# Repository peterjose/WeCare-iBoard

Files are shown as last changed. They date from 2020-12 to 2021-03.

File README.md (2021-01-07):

# WeCare-iBoard
WeCare-iBoard is an interactive board developed by the Team Hugo of University of Saarland.
The project is supported by the Human-Computer Interaction group of Saarland University.

The theme of the project is to build interactive robots that bring us together, especially during the Covid situation.

## Description
WeCare-iBoards work in pairs, one for each user. Connected wirelessly, the boards let the two users interact with each other. The user places portable cubes on top of the board and this activates the other iBoard. The iBoard2 actuates, following the placement of the portable cubes on iBoard1, which makes this device tangible and lets users feel more connected. The project aims at letting the users transfer emotions ideally and also do other fun activities like play games. The iBoards are originally designed to be mounted on the wall but later can also be scaled for some portability. 

## Project documentation
Project Documentation can be found under the directory "doc"

## General Commit rules to be followed
* Create branches if working on existing project directories
* Create new folders for storing unit test codes 

## Documentation naming convention
WeCare_iBoard_FileName.extension

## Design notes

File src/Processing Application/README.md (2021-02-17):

# Processing Application
An application to support interfacing with iBoard. Using this application users can send a text message to each other’ board.
The text message is decoded to a symbol/icon, then it is transferred to the other users board. The translation is also visible on the virtual board available on the app.

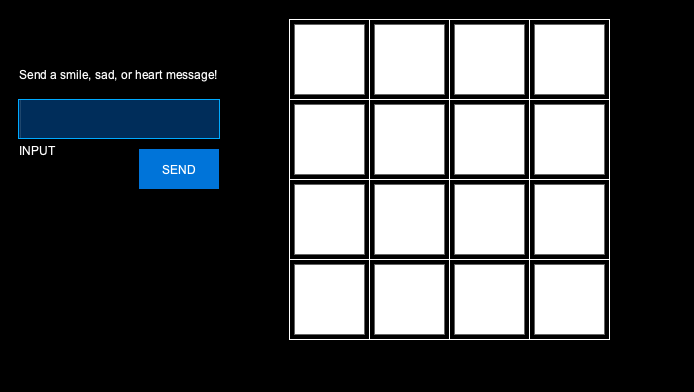
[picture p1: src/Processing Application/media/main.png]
alt main


How it works:

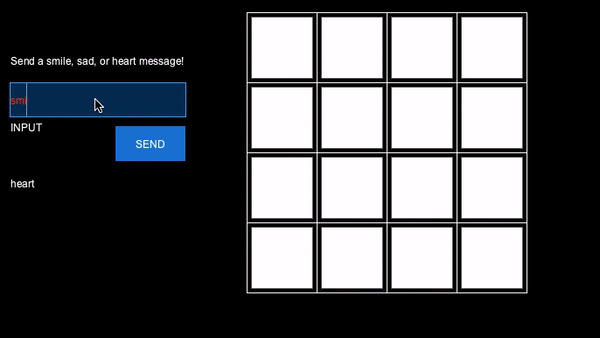
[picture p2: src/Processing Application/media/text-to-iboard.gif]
Alt app


### TODO:
Set a communication channel, board <-> app

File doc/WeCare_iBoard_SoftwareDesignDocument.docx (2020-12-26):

WeCare i-Board

Software Design Document

By

Team Hugo

## 1. Project Overview

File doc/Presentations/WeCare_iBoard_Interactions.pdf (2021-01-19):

# Interactions

# User Scenarios

# List

## - Emoji - Play Tic-Tac-Toe - Remote Collaboration(Task status bar) - *Modified Marble Answering Machine

# Emoji

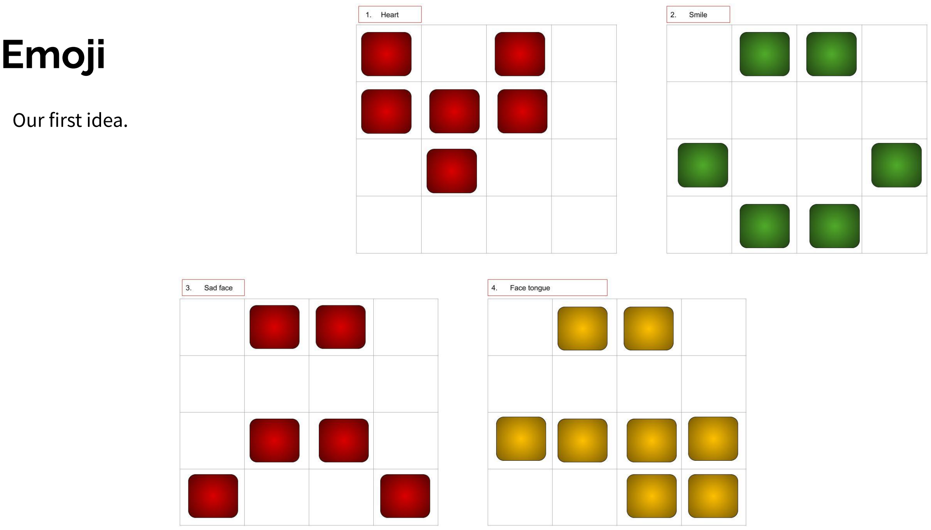
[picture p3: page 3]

Our first idea.

# Play a Game - tic-tac-toe

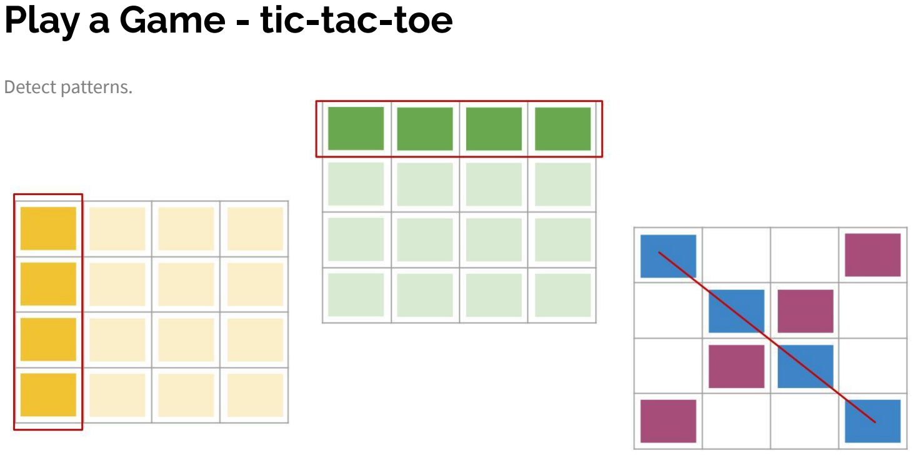
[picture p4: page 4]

Detect patterns.

# Remote Collaboration

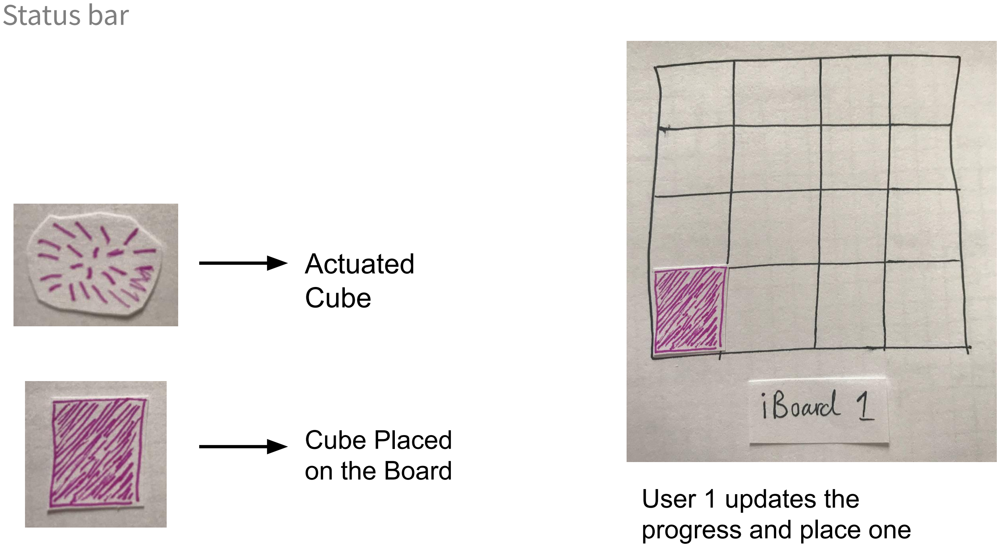
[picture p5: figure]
Status bar; Actuated Cube; Cube Placed on the Board; User 1 updates the progress and place one

cube on the board.

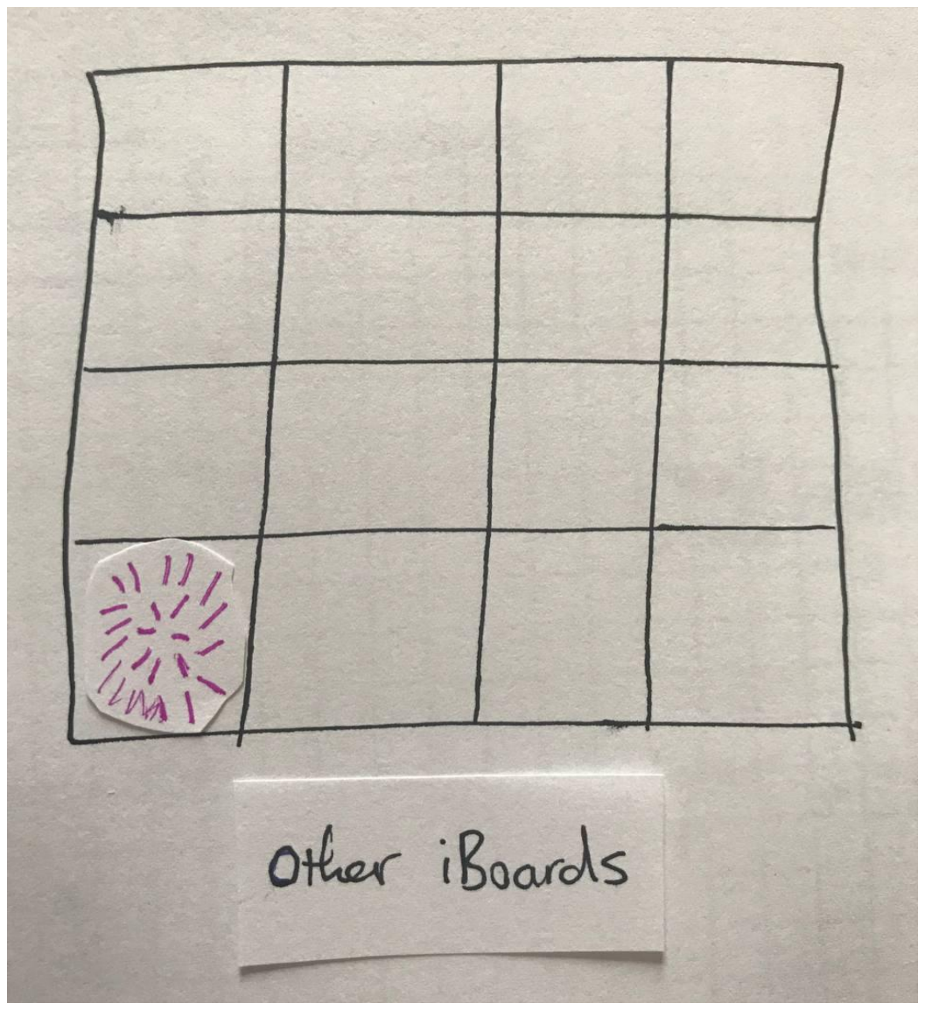
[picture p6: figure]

Other boards get the
update.

# Remote Collaboration

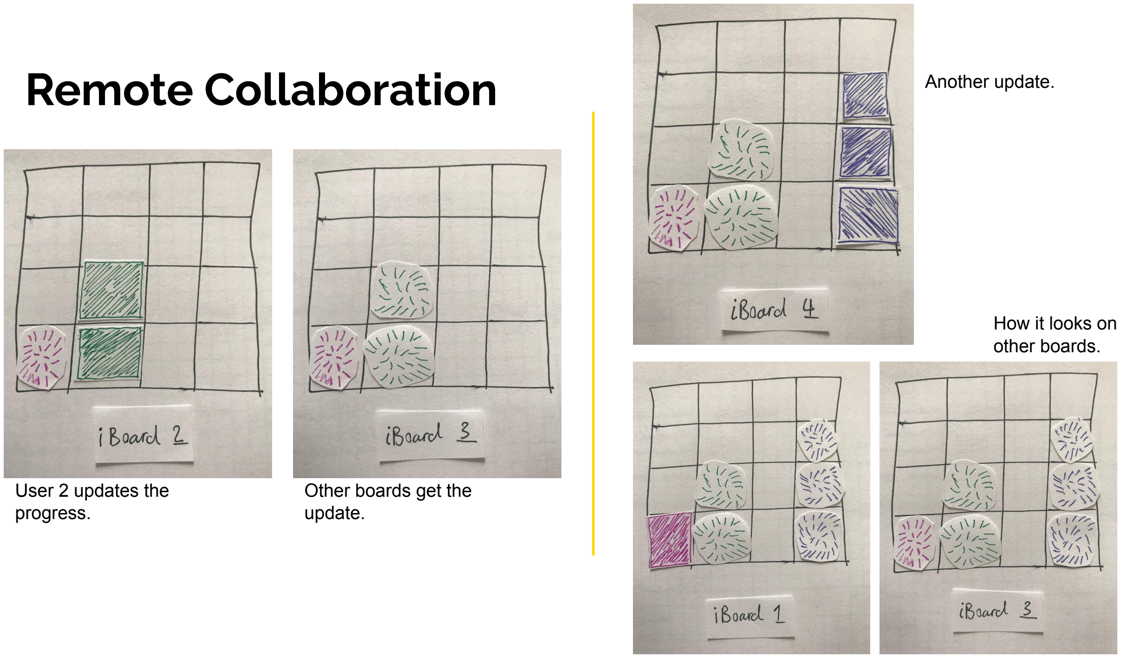
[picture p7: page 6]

User 2 updates the
progress.

Other boards get the
update.

Another update.

How it looks on
other boards.

# *Modified Marble Answering Machine

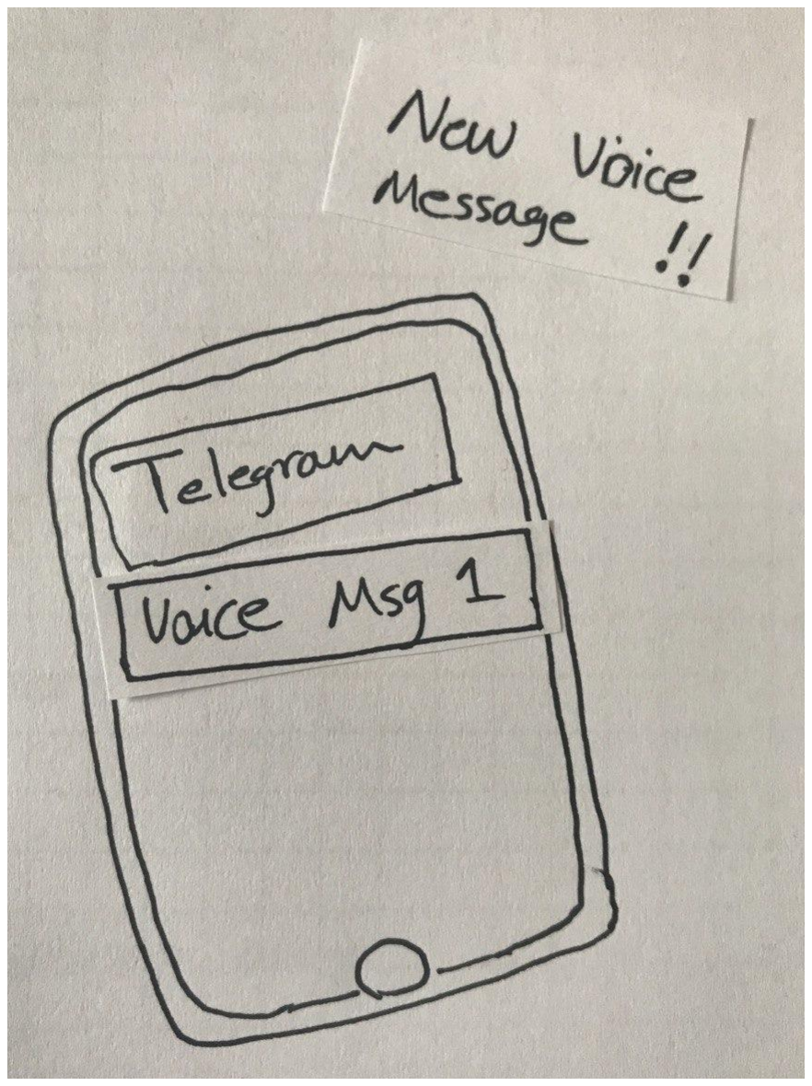
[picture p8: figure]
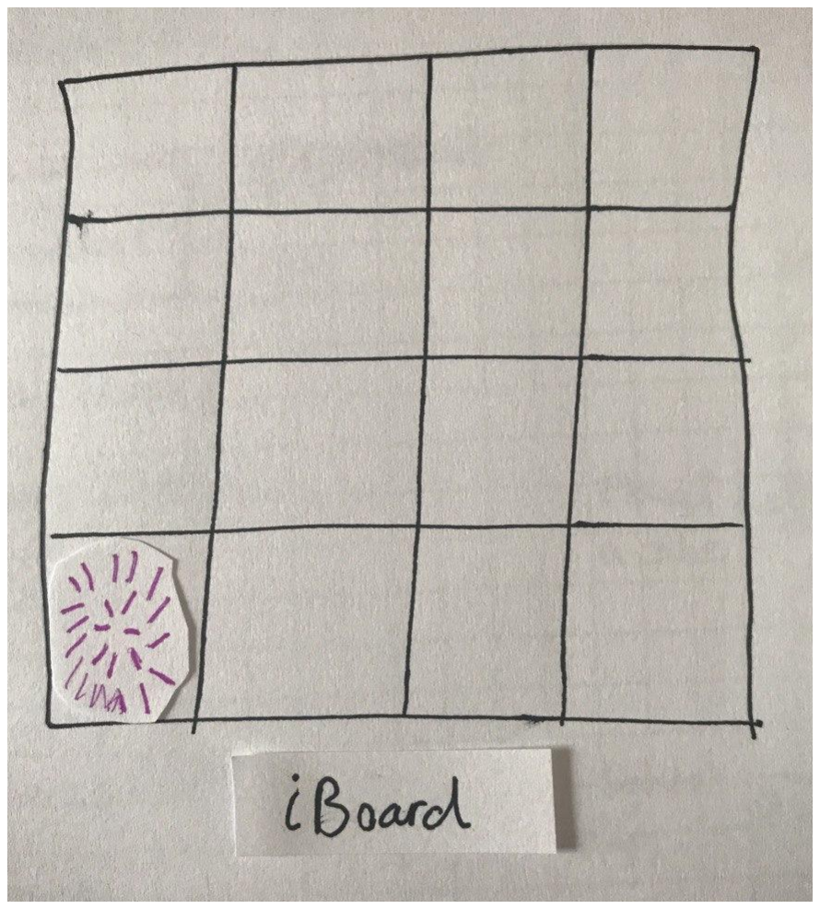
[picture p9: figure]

New voice
messages
arrives.

One cube pops up.

# *Modified Marble Answering Machine

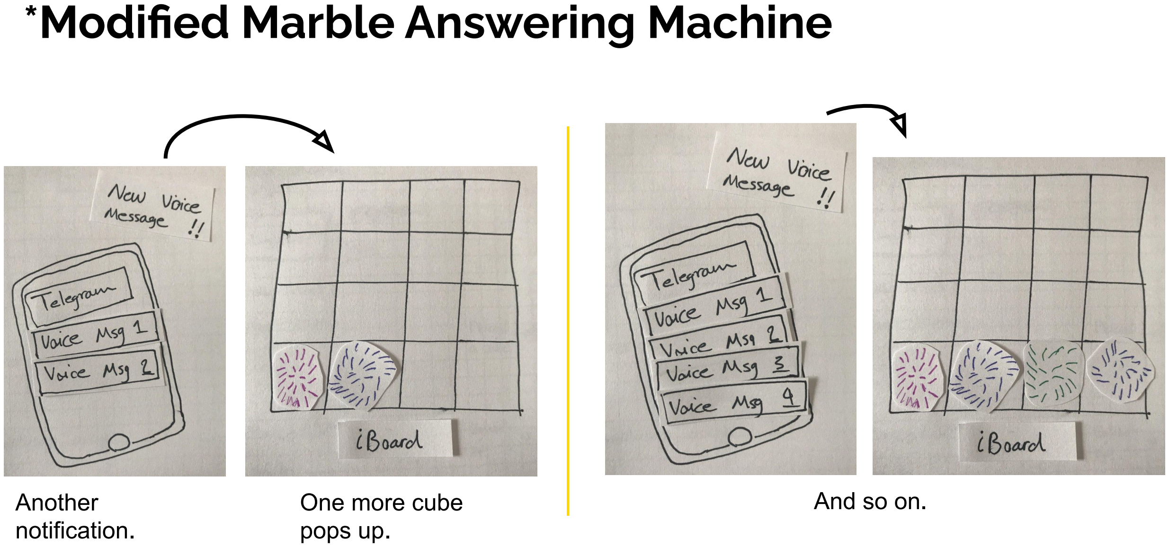
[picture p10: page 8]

Another
notification.

One more cube
pops up.

And so on.

# *Modified Marble Answering Machine

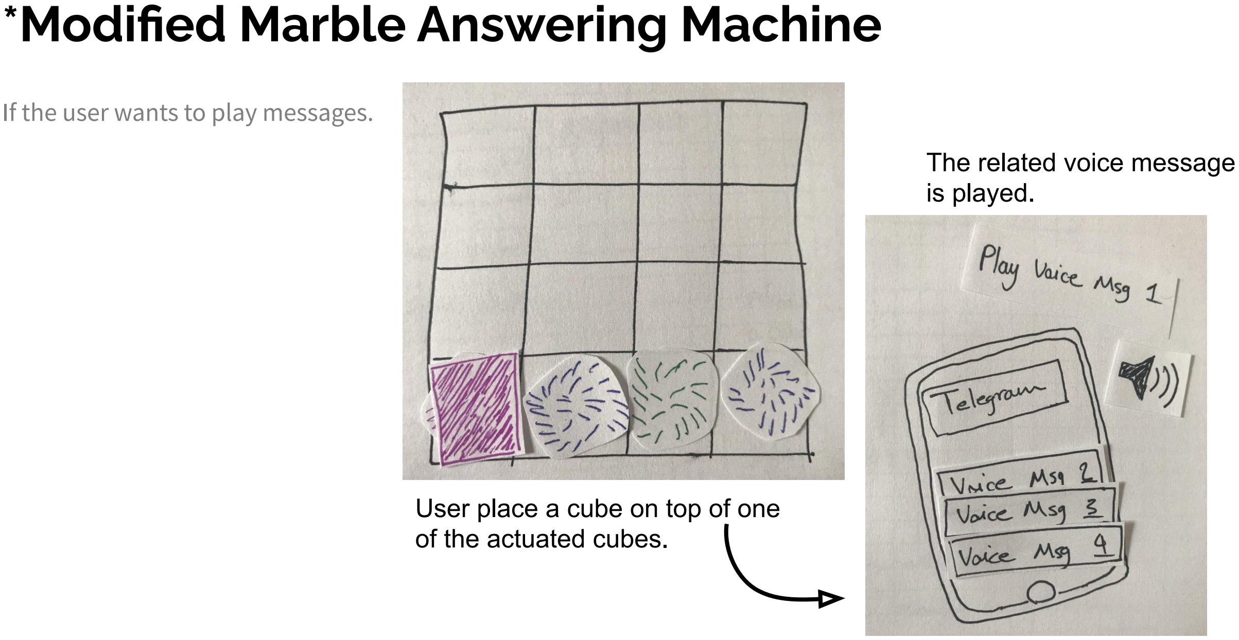
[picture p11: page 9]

If the user wants to play messages.

User place a cube on top of one of the actuated cubes.

The related voice message
is played.

# *Modified Marble Answering Machine

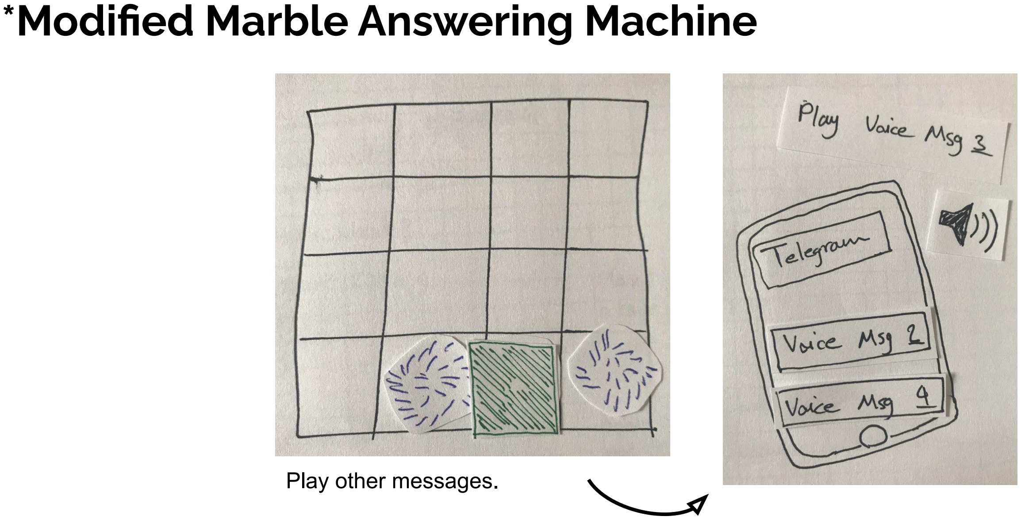
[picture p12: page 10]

Play other messages.

# Mode Switch

### - Hard code - reprogram the board for each scenario - Use buttons - Mode switch patterns - Easy transition

# Mode Switch

## Using Patterns

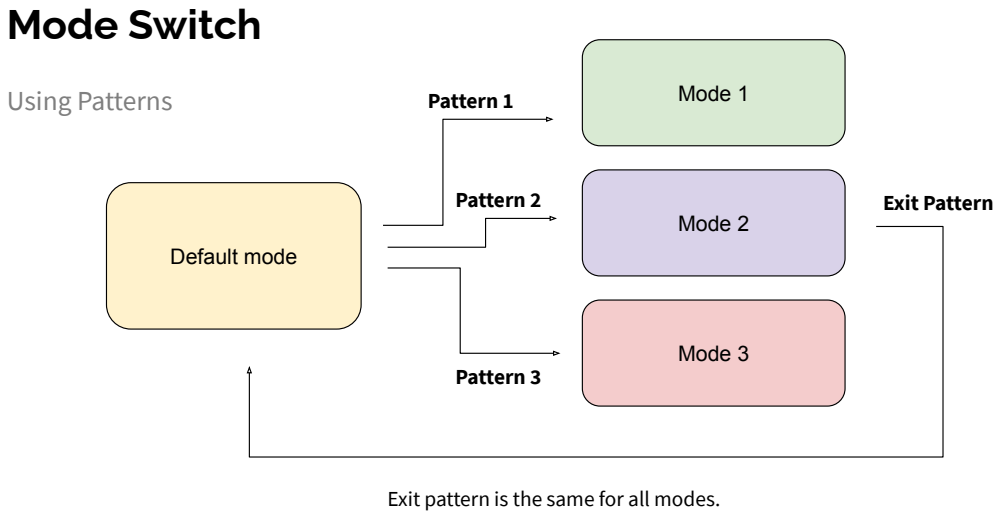
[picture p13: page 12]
Default mode; Mode 1; Mode 2; Mode 3; Exit Pattern; Pattern 1; Pattern 2; Pattern 3

Exit pattern is the same for all modes.

# Mode Switch

## Using Patterns

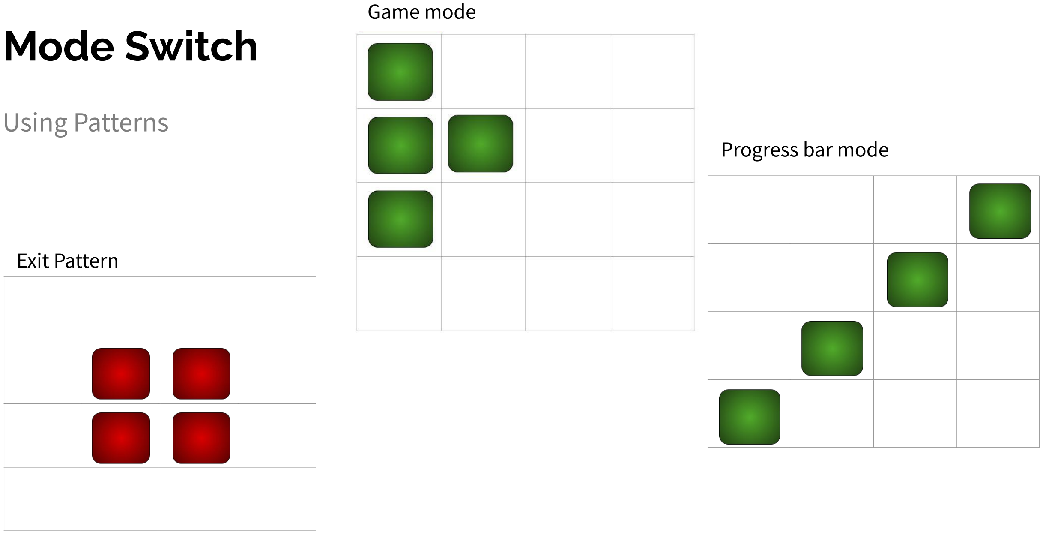
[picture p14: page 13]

Progress bar mode

Exit Pattern

Game mode

# Transition between modes

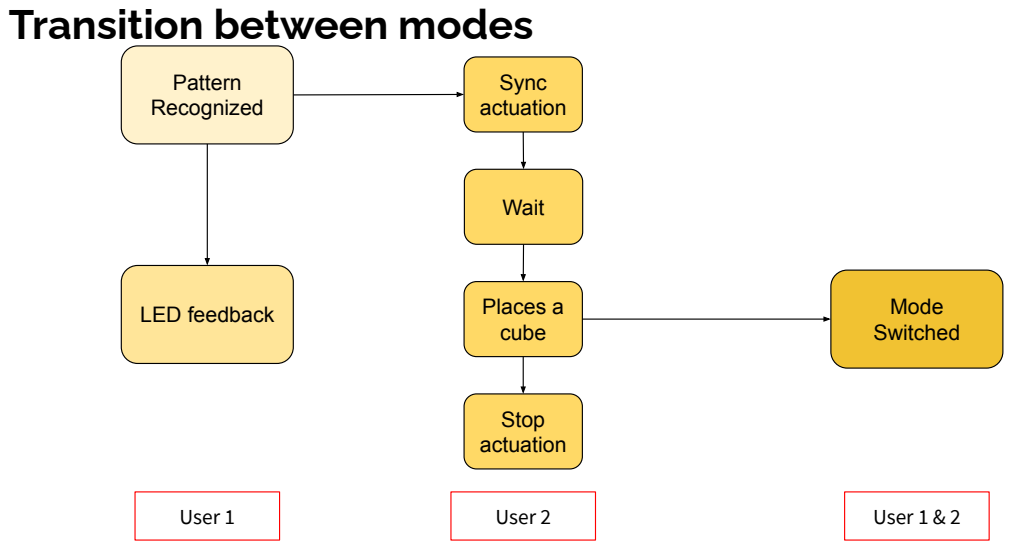
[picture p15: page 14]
Pattern Recognized; LED feedback; Sync actuation; Wait; Places a cube; Mode Switched; User 1; User 2; User 1 & 2; Stop actuation

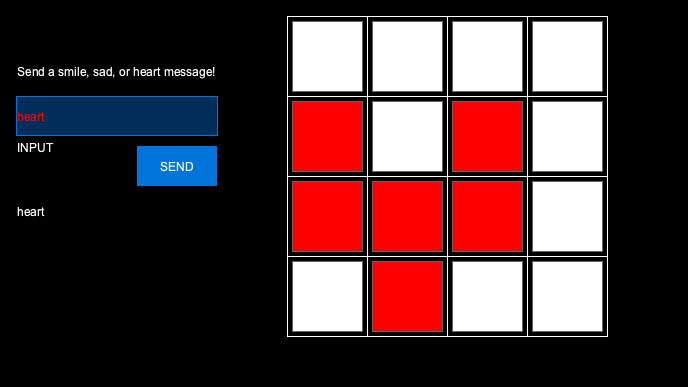
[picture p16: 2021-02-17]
src/Processing Application/media/heart.png

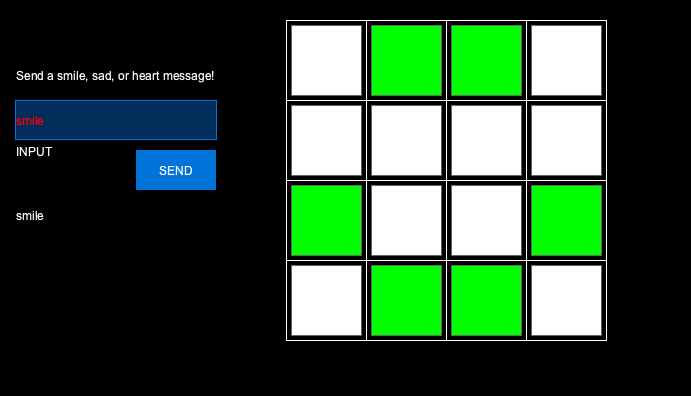
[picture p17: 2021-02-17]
src/Processing Application/media/smile.png

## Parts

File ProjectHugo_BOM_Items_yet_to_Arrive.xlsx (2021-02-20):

BILL OF MATERIALS ROBOTIC SEMINAR
GROUP NAME | Project Hugo
PART COUNT | 9
TOTAL COST | €148.64
PART NUMBER | PART NAME | DESCRIPTION | PART IMAGE | QUANTITY | UNITS | SUPPLIER / MANUFACTURER / LINK | UNIT COST | TOTAL PART COST
B01N2N7LZA | Arduino Mega shield | To make the connections to the modular peices |  | 2 | Nos | https://www.amazon.de/-/en/Wingo-Engineer-Baite-02/dp/B01N2N7LZA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 | €16.00 | €32.00
B01EV70C78 | Jumper wires | For connection betweeen components 40x M-M 40x F-M 40x F-F Header strips |  | 2 | Nos | https://www.amazon.de/-/en/KeeYees-120pcs-Jumper-Arduino-Raspberry/dp/B07KCD7GS7?s=ce-de | €8.00 | €16.00
 |  |  |  |  |  |  | Total | €48.00
 |  | Lab Consumables | (Order only if Not available in the LAB)
B07GXN2521 | JST connector(L) | For the power supply (in total 32 peices) |  | 4 | Nos | https://www.amazon.de/ILS-Micro-1-5mm-Connector-Cables/dp/B07GXN2521 | €8.71 | €34.84
B00KKVJ1H2 | Power Supply 5v 20A | For powering all the board |  | 1 | Nos | https://www.amazon.de/Supply-Netzteil-WS2801-WS2812-WS2812B/dp/B00KKVJ1H2 | €32.00 | €32.00
168284GR | Soldering dot Board | Custom PCB boards |  | 1 | Nos | https://www.amazon.de/dp/B08BR2CQRX | €16.00 | €16.00
B07PNYJDZ7 | Acrylic Glue(L) | Glue to stick all the parts of the board |  | 1 | Nos | https://www.amazon.de/-/en/S-PolyBond%C2%AE-Acrylic-plexiglass-adhesive-suitable/dp/B07PNYJDZ7 | €9.90 | €9.90
B07Y1TJH5R | Power Supply cables | Power cable of the power supply |  | 1 | Nos | https://www.amazon.de/dp/B07Y1TJH5R | €6.00 | €6.00
B00XZ7IEAS | Heat shrink tube(L) | For making the wire connection proper and |  | 1 | Nos | https://www.amazon.de/-/en/Aurora-trading-Shrink-Tubing-Choose-colours/dp/B00XZ7IEAS | €1.90 | €1.90
 |  |  |  |  |  |  | Sub Tatal | €100.64
 |  |  | TOTAL PARTS | 9 |  |  | TOTAL | €148.64

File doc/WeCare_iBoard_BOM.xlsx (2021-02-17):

BILL OF MATERIALS ROBOTIC SEMINAR
GROUP NAME | Project Hugo
PART COUNT | 109
TOTAL COST | €447.75
PART NUMBER | PART NAME | DESCRIPTION | PART IMAGE | QUANTITY | UNITS | SUPPLIER / MANUFACTURER / LINK | UNIT COST | TOTAL PART COST
B089SP1MSN | Acrylic Sheets | For the board design and gears |  | 4 | Nos | https://www.amazon.de/-/en/Plexiglas%C2%AE-versatile-unbreakable-branded-white-translucent/dp/B089SP1MSN | €15.00 | €60.00
B075QM9GKW | Plywood Sheets | For Outer body of both boxes(100 sq cm) |  | 10 | Sheets | https://www.amazon.de/-/en/Creative-Plywood-Chipboard-Pyrography-Openwork/dp/B075QM9GKW | €16.45 | €16.45
RBS10195 | Micro Servo | Actuating the blocks of the interactive display |  | 35 | Nos | https://www.roboter-bausatz.de/246/sg90-9g-micro-servomotor | €2.00 | €70.00
B01N2N7LZA | Arduino Mega shield | To make the connections to the modular peices |  | 2 | Nos | https://www.amazon.de/-/en/Wingo-Engineer-Baite-02/dp/B01N2N7LZA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 | €16.00 | €32.00
A000067 | Arduino Mega | Micro controller that controls the sensors and actuators |  | 2 | Nos | https://www.amazon.de/Mikrocontroller-ATmega2560-ATMEGA16U2-USB-Kabel-Kompatibel/dp/B01MA5BLQI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 | €15.00 | €30.00
B075F3KG2K | Reed Switch | To sense the block placement by the user (in total 32 peices) |  | 4 | Nos | https://www.amazon.de/EsportsMJJ-Wechsler-Magnetschalter-Switches-Switch/dp/B075F3KG2K?hvadid=354652109717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 | €4.99 | €19.96
B01N0GIHFG | Neo Pixel 1 | To highlight the activated block as per design (in total 32 peices) |  | 1 | Nos | https://www.amazon.de/-/en/CHINLY-Pieces-WS2812B-Addressable-Heatsink/dp/B01N0GIHFG?s=lighting | €16.00 | €16.00
B01EV70C78 | Jumper wires | For connection betweeen components 40x M-M 40x F-M 40x F-F Header strips |  | 2 | Nos | https://www.amazon.de/-/en/KeeYees-120pcs-Jumper-Arduino-Raspberry/dp/B07KCD7GS7?s=ce-de | €8.00 | €16.00
S-08-04-N | Permanent Magnet | This is used to activate the reed switch sensor (in total 32 peices) |  | 40 | Nos | https://www.supermagnete.de/scheibenmagnete-neodym/scheibenmagnet-8mm-4mm_S-08-04-N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 | €0.35 | €14.00
B06Y1ZPNMS | ESP8266 | Controller that is used for wireless connection |  | 2 | Nos | https://www.amazon.de/AZDelivery-NodeMCU-ESP8266-ESP-12E-Development/dp/B06Y1ZPNMS?hvadid=310638483583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 | €6.00 | €12.00
B00IYUWT2A | Resistors | 10 KOhm for the sensor design 30x Resistors pack (in total 32 peices) |  | 2 | Nos | https://www.amazon.de/Widerstand-St%C3%BCck-Kohleschicht-Widerst%C3%A4nde-Resistor/dp/B00IYUWT2A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 | €3.15 | €6.30
 |  |  |  |  |  |  | Total | €292.71
 |  | Lab Consumables | (Order only if Not available in the LAB)
B07GXN2521 | JST connector(L) | For the power supply (in total 32 peices) |  | 4 | Nos | https://www.amazon.de/ILS-Micro-1-5mm-Connector-Cables/dp/B07GXN2521 | €8.71 | €34.84
B00KKVJ1H2 | Power Supply 5v 20A | For powering all the board |  | 1 | Nos | https://www.amazon.de/Supply-Netzteil-WS2801-WS2812-WS2812B/dp/B00KKVJ1H2 | €32.00 | €32.00
168284GR | Soldering dot Board | Custom PCB boards |  | 1 | Nos | https://www.amazon.de/dp/B08BR2CQRX | €16.00 | €16.00
AK-B7116091(L) | Micro USB cable | USB cable to connect the ESP for programming and powering |  | 2 | Nos | https://www.amazon.de/Anker-Ladekabel-vergoldeten-Steckern-Smartphones/dp/B01DEMTOQ6?hvadid=309827211017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 | €8.00 | €16.00
B075LMP74F | Conductive copper wire(L) | For electrical wiring |  | 1 | Nos | https://www.amazon.de/-/en/0-25-Plated-Copper-Insulation-Wrapping/dp/B075LMP74F | €15.10 | €15.10
B07PNYJDZ7 | Acrylic Glue(L) | Glue to stick all the parts of the board |  | 1 | Nos | https://www.amazon.de/-/en/S-PolyBond%C2%AE-Acrylic-plexiglass-adhesive-suitable/dp/B07PNYJDZ7 | €9.90 | €9.90
B00DCMK102 | Soldering Iron(L) | For soldering |  | 1 | Nos | https://www.amazon.de/Unbekannt-Fein-L%C3%B6tkolben-230V-30W-L%C3%B6tkolben/dp/B00DCMK102?hvadid=308574982278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 | €7.80 | €7.80
B07Y1TJH5R | Power Supply cables | Power cable of the power supply |  | 1 | Nos | https://www.amazon.de/dp/B07Y1TJH5R | €6.00 | €6.00
B07K8PQ4B5 | Breadboards(L) | For testing |  | 1 | Nos | https://www.amazon.de/dp/B07K8PQ4B5 | €4.80 | €4.80
B07QKYGGJ4 | Soldering Led(L) | For soldering |  | 1 | Nos | https://www.amazon.de/Starnearby-Kolophonium-Flussmittel-L%C3%B6tmittel-Durchmesser/dp/B07QKYGGJ4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 | €4.60 | €4.60
2615GG01JA | Glue sticks(L) | Glue sticks for glue gun |  | 1 | Nos | https://www.amazon.de/-/en/Multipurpose-Accessory-Temperature-Plastic-Ceramics/dp/B004G98SSC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 | €3.10 | €3.10
4C-RNJD-GS1W | Cable Tie(L) | To arrange the cables properly |  | 1 | Nos | https://www.amazon.de/-/en/Cable-ties/dp/B007N2MQQ4 | €3.00 | €3.00
B00XZ7IEAS | Heat shrink tube(L) | For making the wire connection proper and |  | 1 | Nos | https://www.amazon.de/-/en/Aurora-trading-Shrink-Tubing-Choose-colours/dp/B00XZ7IEAS | €1.90 | €1.90
 |  |  |  |  |  |  | Sub Tatal | €155.04
 |  |  | TOTAL PARTS | 109 |  |  | TOTAL | €447.75

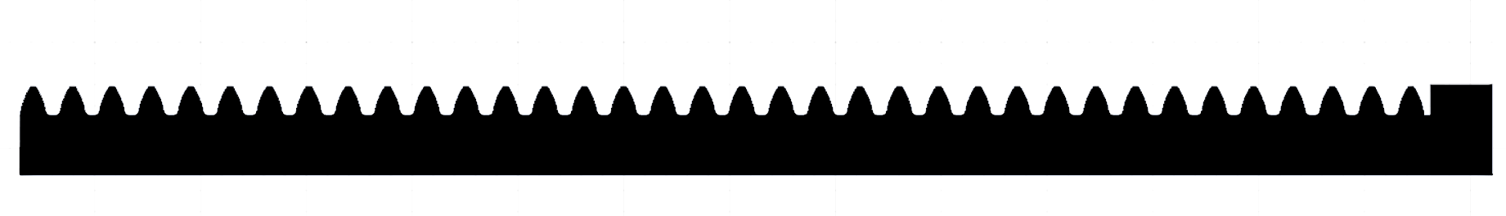
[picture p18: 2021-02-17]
3d-models/Individual Parts/Laser Cut Files/Rack/Rack2.png

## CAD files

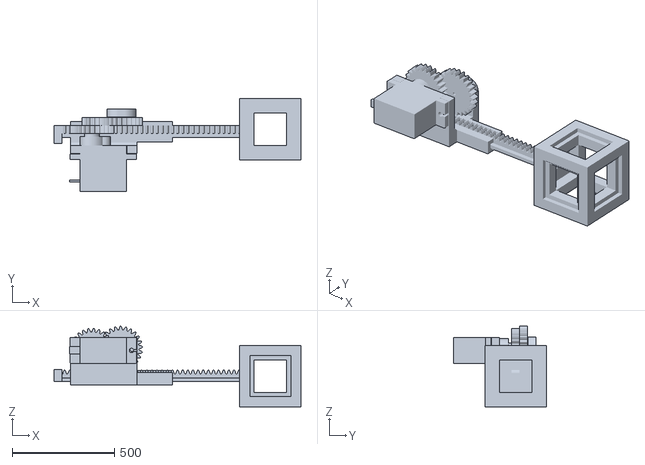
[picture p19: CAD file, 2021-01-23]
3d-models/Hugo Body Final.stl
1209.5 x 453.2 x 394.3

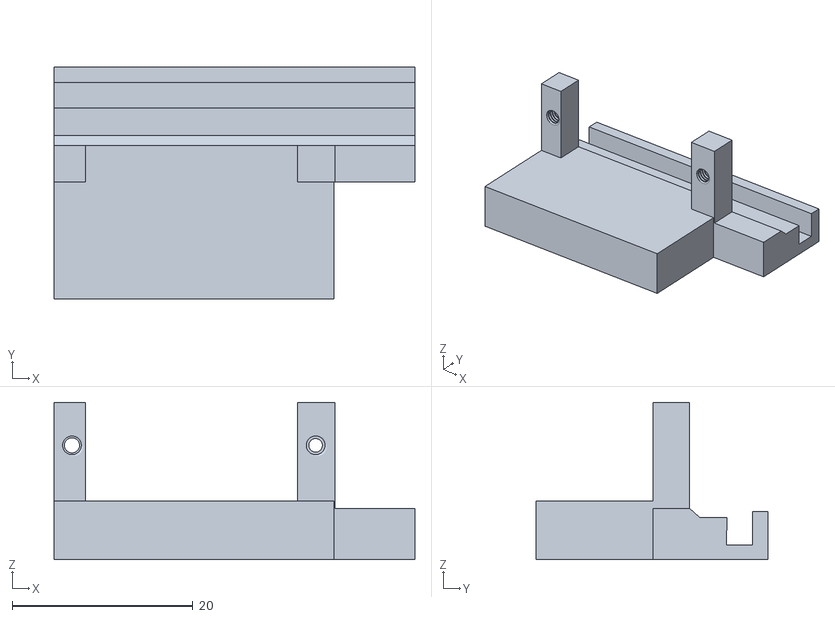
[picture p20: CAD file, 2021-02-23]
3d-models/Individual Parts/3D Print Files/Servo Base.stl
40.0 x 25.8 x 17.4

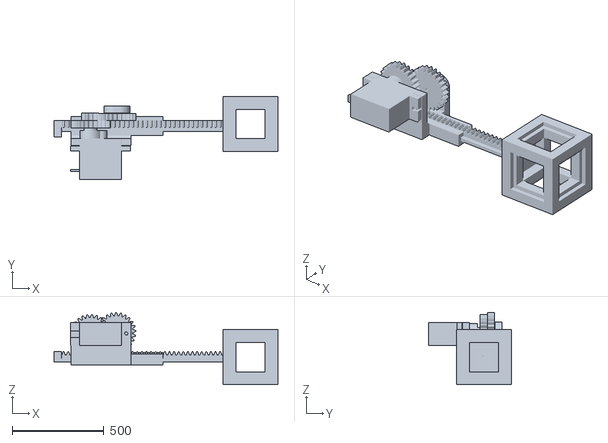
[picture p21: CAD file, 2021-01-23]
3d-models/Hugo Body v10.stl
1222.5 x 453.2 x 394.3

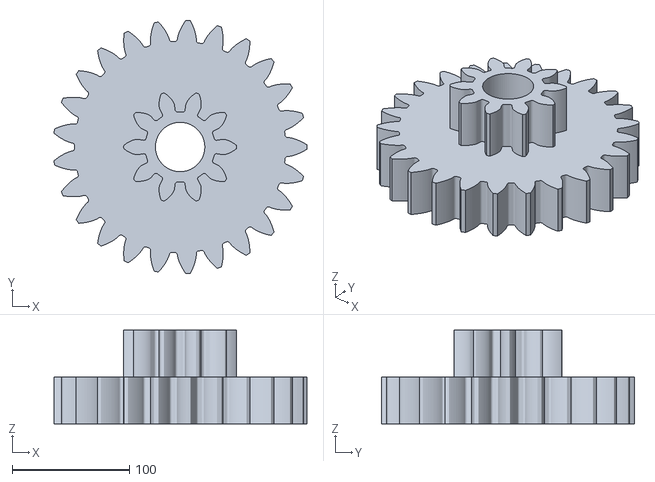
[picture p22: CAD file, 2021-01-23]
3d-models/Hugo Servo Gear v3.stl
215.4 x 215.8 x 80.0

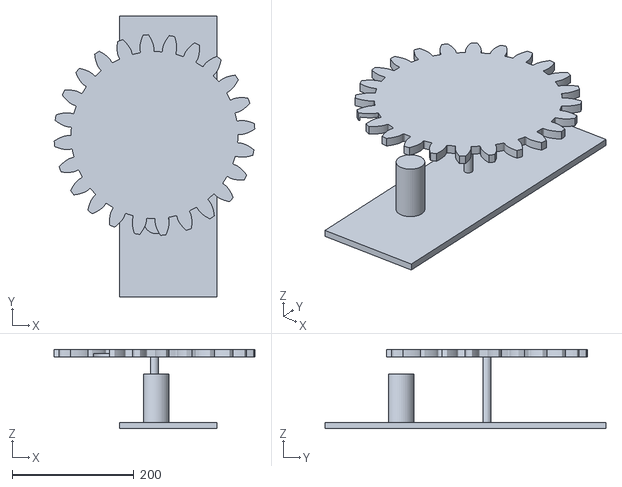
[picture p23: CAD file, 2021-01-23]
3d-models/Hugo Gear test v1.stl
329.6 x 461.6 x 130.0

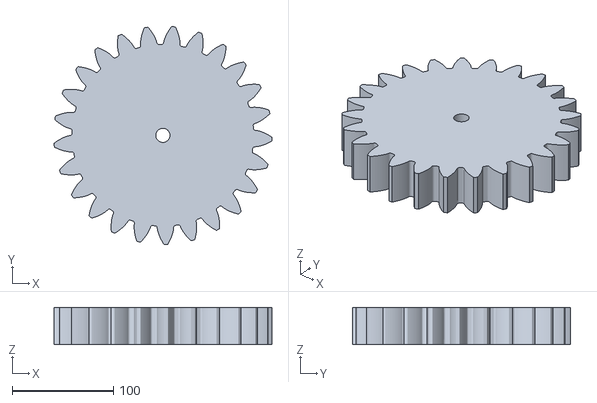
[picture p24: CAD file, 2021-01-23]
3d-models/gear.stl
215.7 x 215.6 x 37.0

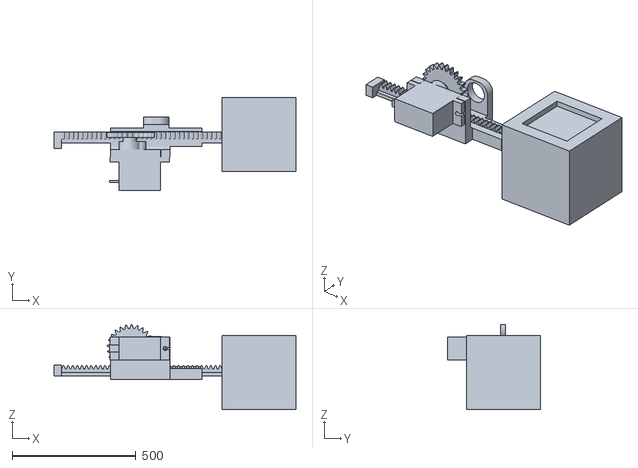
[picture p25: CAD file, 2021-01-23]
3d-models/MeshBody1.stl
977.7 x 377.3 x 344.1

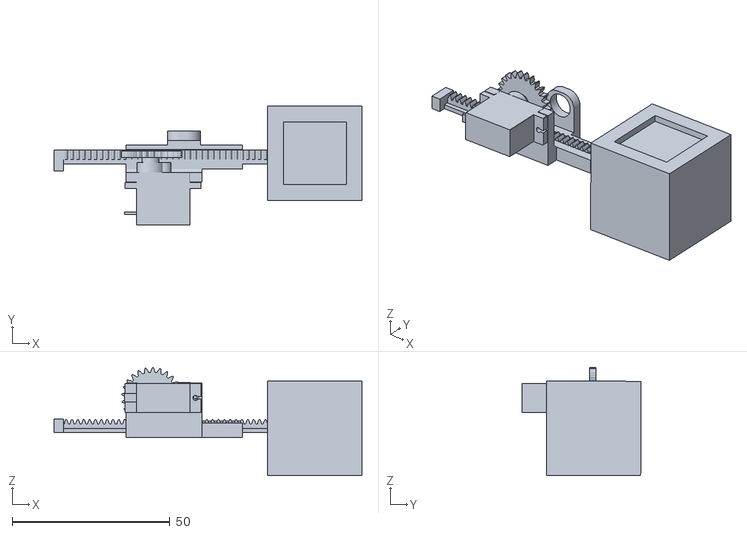
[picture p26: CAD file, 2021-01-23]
3d-models/Hugo Body new v9.stl
97.8 x 37.7 x 34.4

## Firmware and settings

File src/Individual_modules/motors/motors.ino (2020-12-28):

/*
  recieved data to motors
*/ 

#include <Servo.h>
// create servo object to control servos
Servo sm00;   
Servo sm01;  
Servo sm02;
Servo sm03;
Servo sm04;
Servo sm05;
Servo sm06;
Servo sm07;
Servo sm08;
Servo sm09;
Servo sm10;
Servo sm11;
Servo sm12;
Servo sm13;
Servo sm14;
Servo sm15;

// variable to store the servo position
int pos00 = 0;
int pos01 = 0;
int pos02 = 0;
int pos03 = 0;
int pos04 = 0;
int pos05 = 0;
int pos06 = 0;
int pos07 = 0;
int pos08 = 0;
int pos09 = 0;
int pos10 = 0;
int pos11 = 0;
int pos12 = 0;
int pos13 = 0;
int pos14 = 0;
int pos15 = 0;

// new data flag
int newData = 0;

// to save bits of received bytes
int m00 = 0;
int m01 = 0;
int m02 = 0;
int m03 = 0;
int m04 = 0;
int m05 = 0;
int m06 = 0;
int m07 = 0;
int m08 = 0;
int m09 = 0;
int m10 = 0;
int m11 = 0;
int m12 = 0;
int m13 = 0;
int m14 = 0;
int m15 = 0;

// motors status
int stat00 = 0;
int stat01 = 0;
int stat02 = 0;
int stat03 = 0;
int stat04 = 0;
int stat05 = 0;
int stat06 = 0;
int stat07 = 0;
int stat08 = 0;
int stat09 = 0;
int stat10 = 0;
int stat11 = 0;
int stat12 = 0;
int stat13 = 0;
int stat14 = 0;
int stat15 = 0;

// data storage
const byte numBytes = 2;
byte receivedBytes[numBytes];

void setup() {
  Serial.begin(9600);
  Serial.println("Arduino is ready!");
  
  // attach servos on pins 38~53 to servo objects
  sm00.attach(38);
  sm01.attach(39);
  sm02.attach(40);
  sm03.attach(41);
  sm04.attach(42);
  sm05.attach(43);
  sm06.attach(44);
  sm07.attach(45);
  sm08.attach(46);
  sm09.attach(47);
  sm10.attach(48);
  sm11.attach(49);
  sm12.attach(50);
  sm13.attach(51);
  sm14.attach(52);
  sm15.attach(53);

  // set servos initial position
  sm00.write(0);
  sm01.write(0);
  sm02.write(0);
  sm03.write(0);
  sm04.write(0);
  sm05.write(0);
  sm06.write(0);
  sm07.write(0);
  sm08.write(0);
  sm09.write(0);
  sm10.write(0);
  sm11.write(0);
  sm12.write(0);
  sm13.write(0);
  sm14.write(0);
  sm15.write(0);
}

void loop() {
    recvBytes();
    
    if (newData == 1) // call the function only if new data received
      controlMotors();
    else if (newData == 0)
      asm("nop");
}

void recvBytes() {
  // receive 2 bytes (16 bits) from serial port
  // each bit shows the status of one motor
  // read data from serial port
  // Need to set it only when there is new information coming
  //receivedBytes[0] = ;
  //receivedBytes[1] = ;
  // set newData flag to 1 if new data received
}

void controlMotors() {
  // extract the status of each motor from received bytes 
  m00 = bitRead(receivedBytes[0],0);
  m01 = bitRead(receivedBytes[0],1);
  m02 = bitRead(receivedBytes[0],2);
  m03 = bitRead(receivedBytes[0],3);
  m04 = bitRead(receivedBytes[0],4);
  m05 = bitRead(receivedBytes[0],5);
  m06 = bitRead(receivedBytes[0],6);
  m07 = bitRead(receivedBytes[1],7);
  m08 = bitRead(receivedBytes[1],0);
  m09 = bitRead(receivedBytes[1],1);
  m10 = bitRead(receivedBytes[1],2);
  m11 = bitRead(receivedBytes[1],3);
  m12 = bitRead(receivedBytes[1],4);
  m13 = bitRead(receivedBytes[1],5);
  m14 = bitRead(receivedBytes[1],6);
  m15 = bitRead(receivedBytes[1],7);
  
  // motor 0
  if (m00 == 1){
    // activate the block
    // turn on the led
    // push the cube up
    if (stat00 == 1) // if it is already up do nothing
        asm("nop");
    else if (stat00 == 0){
        for (pos00 = 0; pos00 <= 180; pos00 += 1){sm00.write(pos00);}
        stat00 = 1; }} // motor is up, change its status to 1
  else if (m00 == 0) {
    // deactivate the block
    // turn off the led
    // pull the cube down
    if (stat00 == 0) // if it is already down do nothing
        asm("nop");
    else if (stat00 == 1){
        for (pos00 = 180; pos00 >= 0; pos00 -= 1) {sm00.write(pos00);}
        stat00 = 0; }} // motor is down, change its status to 0

  // motor 1
  if (m01 == 1){
    // activate the block
    // turn on the led
    // push the cube up
    if (stat01 == 1) // if it is already up do nothing
        asm("nop");
    else if (stat01 == 0){
        for (pos01 = 0; pos01 <= 180; pos01 += 1){sm01.write(pos01);}
        stat01 = 1; }} // motor is up, change its status to 1
  else if (m01 == 0) {
    // deactivate the block
    // turn off the led
    // pull the cube down
    if (stat01 == 0) // if it is already down do nothing
        asm("nop");
    else if (stat01 == 1){
        for (pos01 = 180; pos01 >= 0; pos01 -= 1) {sm01.write(pos01);}
        stat01 = 0; }} // motor is down, change its status to 0
  
  // motor 2
  if (m02 == 1){
    // activate the block
    // turn on the led
    // push the cube up
    if (stat02 == 1) // if it is already up do nothing
        asm("nop");
    else if (stat02 == 0){
        for (pos02 = 0; pos02 <= 180; pos02 += 1){sm02.write(pos02);}
        stat02 = 1; }} // motor is up, change its status to 1
  else if (m02 == 0) {
    // deactivate the block
    // turn off the led
    // pull the cube down
    if (stat02 == 0) // if it is already down do nothing
        asm("nop");
    else if (stat02 == 1){
        for (pos02 = 180; pos02 >= 0; pos02 -= 1) {sm02.write(pos02);}
        stat02 = 0; }} // motor is down, change its status to 0
  
  // motor 3
  if (m03 == 1){
    // activate the block
    // turn on the led
    // push the cube up
    if (stat03 == 1) // if it is already up do nothing
        asm("nop");
    else if (stat03 == 0){
        for (pos03 = 0; pos03 <= 180; pos03 += 1){sm03.write(pos03);}
        stat03 = 1; }} // motor is up, change its status to 1
  else if (m03 == 0) {
    // deactivate the block
    // turn off the led
    // pull the cube down
    if (stat03 == 0) // if it is already down do nothing
        asm("nop");
    else if (stat03 == 1){
        for (pos03 = 180; pos03 >= 0; pos03 -= 1) {sm03.write(pos03);}
        stat03 = 0; }} // motor is down, change its status to 0
  
  // motor 4
  if (m04 == 1){
    // activate the block
    // turn on the led
    // push the cube up
    if (stat04 == 1) // if it is already up do nothing
        asm("nop");
    else if (stat04 == 0){
        for (pos04 = 0; pos04 <= 180; pos04 += 1){sm04.write(pos04);}
        stat04 = 1; }} // motor is up, change its status to 1
  else if (m04 == 0) {
    // deactivate the block
    // turn off the led
    // pull the cube down
    if (stat04 == 0) // if it is already down do nothing
        asm("nop");
    else if (stat04 == 1){
        for (pos04 = 180; pos04 >= 0; pos04 -= 1) {sm04.write(pos04);}
        stat04 = 0; }} // motor is down, change its status to 0

  // motor 5
  if (m05 == 1){
    // activate the block
    // turn on the led
    // push the cube up
    if (stat05 == 1) // if it is already up do nothing
        asm("nop");
    else if (stat05 == 0){
        for (pos05 = 0; pos05 <= 180; pos05 += 1){sm05.write(pos05);}
        stat05 = 1; }} // motor is up, change its status to 1
  else if (m05 == 0) {
    // deactivate the block
    // turn off the led
    // pull the cube down
    if (stat05 == 0) // if it is already down do nothing
        asm("nop");
    else if (stat05 == 1){
        for (pos05 = 180; pos05 >= 0; pos05 -= 1) {sm05.write(pos05);}
        stat05 = 0; }} // motor is down, change its status to 0

  // motor 6
  if (m06 == 1){
    // activate the block
    // turn on the led
    // push the cube up
    if (stat06 == 1) // if it is already up do nothing
        asm("nop");
    else if (stat06 == 0){
        for (pos06 = 0; pos06 <= 180; pos06 += 1){sm06.write(pos06);}
        stat06 = 1; }} // motor is up, change its status to 1
  else if (m06 == 0) {
    // deactivate the block
    // turn off the led
    // pull the cube down
    if (stat06 == 0) // if it is already down do nothing
        asm("nop");
    else if (stat06 == 1){
        for (pos06 = 180; pos06 >= 0; pos06 -= 1) {sm06.write(pos06);}
        stat06 = 0; }} // motor is down, change its status to 0

  // motor 7
  if (m07 == 1){
    // activate the block
    // turn on the led
    // push the cube up
    if (stat07 == 1) // if it is already up do nothing
        asm("nop");
    else if (stat07 == 0){
        for (pos07 = 0; pos07 <= 180; pos07 += 1){sm07.write(pos07);}
        stat07 = 1; }} // motor is up, change its status to 1
  else if (m07 == 0) {
    // deactivate the block
    // turn off the led
    // pull the cube down
    if (stat07 == 0) // if it is already down do nothing
        asm("nop");
    else if (stat07 == 1){
        for (pos07 = 180; pos07 >= 0; pos07 -= 1) {sm07.write(pos07);}
        stat07 = 0; }} // motor is down, change its status to 0

  // motor 8
  if (m08 == 1){
    // activate the block
    // turn on the led
    // push the cube up
    if (stat08 == 1) // if it is already up do nothing
        asm("nop");
    else if (stat08 == 0){
        for (pos08 = 0; pos08 <= 180; pos08 += 1){sm08.write(pos08);}
        stat08 = 1; }} // motor is up, change its status to 1
  else if (m08 == 0) {
    // deactivate the block
    // turn off the led
    // pull the cube down
    if (stat08 == 0) // if it is already down do nothing
        asm("nop");
    else if (stat08 == 1){
        for (pos08 = 180; pos08 >= 0; pos08 -= 1) {sm08.write(pos08);}
        stat08 = 0; }} // motor is down, change its status to 0

  // motor 9
  if (m09 == 1){
    // activate the block
    // turn on the led
    // push the cube up
    if (stat09 == 1) // if it is already up do nothing
        asm("nop");
    else if (stat09 == 0){
        for (pos09 = 0; pos09 <= 180; pos09 += 1){sm09.write(pos09);}
        stat09 = 1; }} // motor is up, change its status to 1
  else if (m09 == 0) {
    // deactivate the block
    // turn off the led
    // pull the cube down
    if (stat09 == 0) // if it is already down do nothing
        asm("nop");
    else if (stat09 == 1){
        for (pos09 = 180; pos09 >= 0; pos09 -= 1) {sm09.write(pos09);}
        stat09 = 0; }} // motor is down, change its status to 0

  // motor 10
  if (m10 == 1){
    // activate the block
    // turn on the led
    // push the cube up
    if (stat10 == 1) // if it is already up do nothing
        asm("nop");
    else if (stat10 == 0){
        for (pos10 = 0; pos10 <= 180; pos10 += 1){sm10.write(pos10);}
        stat10 = 1; }} // motor is up, change its status to 1
  else if (m10 == 0) {
    // deactivate the block
    // turn off the led
    // pull the cube down
    if (stat10 == 0) // if it is already down do nothing
        asm("nop");
    else if (stat10 == 1){
        for (pos10 = 180; pos10 >= 0; pos10 -= 1) {sm10.write(pos10);}
        stat10 = 0; }} // motor is down, change its status to 0

  // motor 11
  if (m11 == 1){
    // activate the block
    // turn on the led
    // push the cube up
    if (stat11 == 1) // if it is already up do nothing
        asm("nop");
    else if (stat11 == 0){
        for (pos11 = 0; pos11 <= 180; pos11 += 1){sm11.write(pos11);}
        stat11 = 1; }} // motor is up, change its status to 1
  else if (m11 == 0) {
    // deactivate the block
    // turn off the led
    // pull the cube down
    if (stat11 == 0) // if it is already down do nothing
        asm("nop");
    else if (stat11 == 1){
        for (pos11 = 180; pos11 >= 0; pos11 -= 1) {sm11.write(pos11);}
        stat11 = 0; }} // motor is down, change its status to 0

  // motor 12
  if (m12 == 1){
    // activate the block
    // turn on the led
    // push the cube up
    if (stat12 == 1) // if it is already up do nothing
        asm("nop");
    else if (stat12 == 0){
        for (pos12 = 0; pos12 <= 180; pos12 += 1){sm12.write(pos12);}
        stat12 = 1; }} // motor is up, change its status to 1
  else if (m12 == 0) {
    // deactivate the block
    // turn off the led
    // pull the cube down
    if (stat12 == 0) // if it is already down do nothing
        asm("nop");
    else if (stat12 == 1){
        for (pos12 = 180; pos12 >= 0; pos12 -= 1) {sm12.write(pos12);}
        stat12 = 0; }} // motor is down, change its status to 0

  // motor 13
  if (m13 == 1){
    // activate the block
    // turn on the led
    // push the cube up
    if (stat13 == 1) // if it is already up do nothing
        asm("nop");
    else if (stat13 == 0){
        for (pos13 = 0; pos13 <= 180; pos13 += 1){sm13.write(pos13);}
        stat13 = 1; }} // motor is up, change its status to 1
  else if (m13 == 0) {
    // deactivate the block
    // turn off the led
    // pull the cube down
    if (stat13 == 0) // if it is already down do nothing
        asm("nop");
    else if (stat13 == 1){
        for (pos13 = 180; pos13 >= 0; pos13 -= 1) {sm13.write(pos13);}
        stat13 = 0; }} // motor is down, change its status to 0

  // motor 14
  if (m14 == 1){
    // activate the block
    // turn on the led
    // push the cube up
    if (stat14 == 1) // if it is already up do nothing
        asm("nop");
    else if (stat14 == 0){
        for (pos14 = 0; pos14 <= 180; pos14 += 1){sm14.write(pos14);}
        stat14 = 1; }} // motor is up, change its status to 1
  else if (m14 == 0) {
    // deactivate the block
    // turn off the led
    // pull the cube down
    if (stat14 == 0) // if it is already down do nothing
        asm("nop");
    else if (stat14 == 1){
        for (pos14 = 180; pos14 >= 0; pos14 -= 1) {sm14.write(pos14);}
        stat14 = 0; }} // motor is down, change its status to 0

  // motor 15
  if (m15 == 1){
    // activate the block
    // turn on the led
    // push the cube up
    if (stat15 == 1) // if it is already up do nothing
        asm("nop");
    else if (stat15 == 0){
        for (pos15 = 0; pos15 <= 180; pos15 += 1){sm15.write(pos15);}
        stat15 = 1; }} // motor is up, change its status to 1
  else if (m15 == 0) {
    // deactivate the block
    // turn off the led
    // pull the cube down
    if (stat15 == 0) // if it is already down do nothing
        asm("nop");
    else if (stat15 == 1){
        for (pos15 = 180; pos15 >= 0; pos15 -= 1) {sm15.write(pos15);}
        stat15 = 0; }} // motor is down, change its status to 0

}

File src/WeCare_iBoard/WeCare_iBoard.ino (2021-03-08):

/**
 * @file WeCare_iBoard.ino
 * @author Team Hugo
 * @brief WeCare_iBoard is a project developed for remote interaction between two or more people using 
 * a interactive board.
 * 
 * Software Modules used:
 * DebugPrint : For debug related functionalities
 * CubeModule : Provide a single point data point for all the info related to modular peice designed
 * Sensor : 
 * 
 * Libraries used:
 * Servo by Michael Margolis, Arduino version 1.1.7
 * Adafruit NeoPixel version 1.7.0
 * Adafruit TiCoServo version 1.0.4
 * 
 * 
 * @version 0.1
 * @date 2020-12-27
 * 
 * @copyright Copyright (c) 2020
 * 
 */

/*
TODO: 
  Additional Serial connector for ESP communication
  Packet Creator
  Backup - Use of CBOR for data transfer or Custom protocol (bit map)
  MQTT feasiblity - ESP
  EEPROM module for the actuator calibration information
  Make interactiveBoard Dynamic
*/

#include <avr/wdt.h>

// comment the following line to disable the Debug printing over the UART
#define DEBUG_ENABLE
#include "DebugPrint.hpp"

#include "config.hpp"
#include "bsp.hpp"
#include "CubeModule.hpp"
#include "NetworkCommunicationModule.hpp"
#include "SoftTimer.hpp"
#include "TimingConfig.hpp"

// Interactive Board
CubeModule_t interactiveBoard[16];

// pixel count of the interactive board
int pixelCount = sizeof(interactiveBoard) / sizeof(CubeModule_t);

/**
 * @brief 
 * 
 */
void DummyInitfn()
{
  interactiveBoard[0].sensorPin = SWITCH01;
  interactiveBoard[0].actuatorPin = MOTOR01;
  interactiveBoard[0].actuationActivated = SENSOR_INACTIVE;
  interactiveBoard[0].actuatorLowSetting = MIN_POSITION_DEFAULT;
  interactiveBoard[0].actuatorHighSetting  = MAX_POSITION_DEFAULT;
#ifdef NORMAL_SERVO
  interactiveBoard[0].actuatorMode = NO_UPDATE_MODE;
#else
  interactiveBoard[0].actuatorMode = DEACTIVE_MODE;
#endif /* NORMAL_SERVO */

  interactiveBoard[1].sensorPin = SWITCH02;
  interactiveBoard[1].actuatorPin = MOTOR02;
  interactiveBoard[1].actuationActivated = SENSOR_INACTIVE;
  interactiveBoard[1].actuatorLowSetting = MIN_POSITION_DEFAULT;
  interactiveBoard[1].actuatorHighSetting  = MAX_POSITION_DEFAULT;
#ifdef NORMAL_SERVO
  interactiveBoard[1].actuatorMode = NO_UPDATE_MODE;
#else
  interactiveBoard[1].actuatorMode = DEACTIVE_MODE;
#endif /* NORMAL_SERVO */

  interactiveBoard[2].sensorPin = SWITCH03;
  interactiveBoard[2].actuatorPin = MOTOR03;
  interactiveBoard[2].actuationActivated = SENSOR_INACTIVE;
  interactiveBoard[2].actuatorLowSetting = MIN_POSITION_DEFAULT;
  interactiveBoard[2].actuatorHighSetting  = MAX_POSITION_DEFAULT;
#ifdef NORMAL_SERVO
  interactiveBoard[2].actuatorMode = NO_UPDATE_MODE;
#else
  interactiveBoard[2].actuatorMode = DEACTIVE_MODE;
#endif /* NORMAL_SERVO */

  interactiveBoard[3].sensorPin = SWITCH04;
  interactiveBoard[3].actuatorPin = MOTOR04;
  interactiveBoard[3].actuationActivated = SENSOR_INACTIVE;
  interactiveBoard[3].actuatorLowSetting = MIN_POSITION_DEFAULT;
  interactiveBoard[3].actuatorHighSetting  = MAX_POSITION_DEFAULT;
#ifdef NORMAL_SERVO
  interactiveBoard[3].actuatorMode = NO_UPDATE_MODE;
#else
  interactiveBoard[3].actuatorMode = DEACTIVE_MODE;
#endif /* NORMAL_SERVO */

  interactiveBoard[4].sensorPin = SWITCH05;
  interactiveBoard[4].actuatorPin = MOTOR05;
  interactiveBoard[4].actuationActivated = SENSOR_INACTIVE;
  interactiveBoard[4].actuatorLowSetting = MIN_POSITION_DEFAULT;
  interactiveBoard[4].actuatorHighSetting  = MAX_POSITION_DEFAULT;
#ifdef NORMAL_SERVO
  interactiveBoard[4].actuatorMode = NO_UPDATE_MODE;
#else
  interactiveBoard[4].actuatorMode = DEACTIVE_MODE;
#endif /* NORMAL_SERVO */

  interactiveBoard[5].sensorPin = SWITCH06;
  interactiveBoard[5].actuatorPin = MOTOR06;
  interactiveBoard[5].actuationActivated = SENSOR_INACTIVE;
  interactiveBoard[5].actuatorLowSetting = MIN_POSITION_DEFAULT;
  interactiveBoard[5].actuatorHighSetting  = MAX_POSITION_DEFAULT;
#ifdef NORMAL_SERVO
  interactiveBoard[5].actuatorMode = NO_UPDATE_MODE;
#else
  interactiveBoard[5].actuatorMode = DEACTIVE_MODE;
#endif /* NORMAL_SERVO */

  interactiveBoard[6].sensorPin = SWITCH07;
  interactiveBoard[6].actuatorPin = MOTOR07;
  interactiveBoard[6].actuationActivated = SENSOR_INACTIVE;
  interactiveBoard[6].actuatorLowSetting = MIN_POSITION_DEFAULT;
  interactiveBoard[6].actuatorHighSetting  = MAX_POSITION_DEFAULT;
  interactiveBoard[6].actuatorMode = NO_UPDATE_MODE;

  interactiveBoard[7].sensorPin = SWITCH08;
  interactiveBoard[7].actuatorPin = MOTOR08;
  interactiveBoard[7].actuationActivated = SENSOR_INACTIVE;
  interactiveBoard[7].actuatorLowSetting = MIN_POSITION_DEFAULT;
  interactiveBoard[7].actuatorHighSetting  = MAX_POSITION_DEFAULT;
  interactiveBoard[7].actuatorMode = NO_UPDATE_MODE;

  interactiveBoard[8].sensorPin = SWITCH09;
  interactiveBoard[8].actuatorPin = MOTOR09;
  interactiveBoard[8].actuationActivated = SENSOR_INACTIVE;
  interactiveBoard[8].actuatorLowSetting = MIN_POSITION_DEFAULT;
  interactiveBoard[8].actuatorHighSetting  = MAX_POSITION_DEFAULT;
  interactiveBoard[8].actuatorMode = NO_UPDATE_MODE;

  interactiveBoard[9].sensorPin = SWITCH10;
  interactiveBoard[9].actuatorPin = MOTOR10;
  interactiveBoard[9].actuationActivated = SENSOR_INACTIVE;
  interactiveBoard[9].actuatorLowSetting = MIN_POSITION_DEFAULT;
  interactiveBoard[9].actuatorHighSetting  = MAX_POSITION_DEFAULT;
  interactiveBoard[9].actuatorMode = NO_UPDATE_MODE;

  interactiveBoard[10].sensorPin = SWITCH11;
  interactiveBoard[10].actuatorPin = MOTOR11;
  interactiveBoard[10].actuationActivated = SENSOR_INACTIVE;
  interactiveBoard[10].actuatorLowSetting = MIN_POSITION_DEFAULT;
  interactiveBoard[10].actuatorHighSetting  = MAX_POSITION_DEFAULT;
  interactiveBoard[10].actuatorMode = NO_UPDATE_MODE;

  interactiveBoard[11].sensorPin = SWITCH12;
  interactiveBoard[11].actuatorPin = MOTOR12;
  interactiveBoard[11].actuationActivated = SENSOR_INACTIVE;
  interactiveBoard[11].actuatorLowSetting = MIN_POSITION_DEFAULT;
  interactiveBoard[11].actuatorHighSetting  = MAX_POSITION_DEFAULT;
  interactiveBoard[11].actuatorMode = NO_UPDATE_MODE;

  interactiveBoard[12].sensorPin = SWITCH13;
  interactiveBoard[12].actuatorPin = MOTOR13;
  interactiveBoard[12].actuationActivated = SENSOR_INACTIVE;
  interactiveBoard[12].actuatorLowSetting = MIN_POSITION_DEFAULT;
  interactiveBoard[12].actuatorHighSetting  = MAX_POSITION_DEFAULT;
  interactiveBoard[12].actuatorMode = NO_UPDATE_MODE;

  interactiveBoard[13].sensorPin = SWITCH14;
  interactiveBoard[13].actuatorPin = MOTOR14;
  interactiveBoard[13].actuationActivated = SENSOR_INACTIVE;
  interactiveBoard[13].actuatorLowSetting = MIN_POSITION_DEFAULT;
  interactiveBoard[13].actuatorHighSetting  = MAX_POSITION_DEFAULT;
  interactiveBoard[13].actuatorMode = NO_UPDATE_MODE;
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

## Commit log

2020-12-27 Added initial framework code for the WeCare iBoard. (code not tested on board)
2020-12-27 Added sensor related code and renamed files (code not tested)
2020-12-27 Updated sensor read logic and added files for network communication
2020-12-28 LED control using Adafruit NeoPixel has been implemented (code not tested)
2020-12-28 Tested in Tinkercad for 5 motors
2020-12-28 Control motors. Tested in Tinkercad for 5 motors.
2020-12-28 Added code for actuator control
2020-12-28 Restructured the folders (motors.ino have been moved another separate folder)
2020-12-30 Minor fixes (code not tested)
    [CubeModule.hpp, WeCare_iBoard.ino]
2021-01-03 Added IPC_communication module for UART communication
2021-01-05 Single motor + led + switch
    [iBoard01.fzz]
2021-01-05 5*5 with simple LED
    [iBoard02.fzz]
2021-01-07 Create actuator_algorithm.cpp
    A file created to keep track of possible actuation scenarios
2021-01-07 Update actuator_algorithm.cpp
    New scenarios added
2021-01-08 Added exceptions to the circular buffer. (code not tested) NOTE: arduino Ide require to enable a flag to accept the use of exceptions so the code is disabled.
2021-01-14 Arduino mega pins assigned.
2021-01-14 Added Serial code based on interrupt (code not tested)
2021-01-14 Updated the functions calls based on latest function prototype (code not tested)
2021-01-15 Code modified to adapt the changes in function prototype
2021-01-15 Updated dummy timer period to 10 second
2021-01-15 Updated the code profile for testing IPC communication. IPC communicaiton based on Interrupt has been tested. Softtimer has been tested Code example of Soft timer can be seen here for reference.
2021-01-15 Added IPC packet TIMEOUT timer
2021-01-15 Changed the function prototype and added debug print statements
2021-01-23 Sample 3D file
    To be catagorized later
    [Hugo Body Final.stl, Hugo Body new v9.stl, Hugo Body v10.stl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]
2021-01-30 Dummy structure code for ESP network connector. (code not tested or compiled for errors)
2021-02-08 modified the functionalities and added board selection method. Fixed minor bug in MQTT_connect()
2021-02-16 Project BOM - Dated 22nd Dec
    [WeCare_iBoard_BOM.xlsx]
2021-02-17 Create Servo Base.stl
    [Servo Base.stl]
2021-02-17 Servo Base Ultimaker file
2021-02-17 Gear 3D Models
2021-02-17 Create Cube face with holes.svg
2021-02-17 Deleted the old cube face without slot for Rack
2021-02-18 Update Servo Base.stl
    [Servo Base.stl]
2021-02-19 Create ProjectHugo_BOM_Items_yet_to_Arrive.xlsx
    Please correct If anything is missing.
    [ProjectHugo_BOM_Items_yet_to_Arrive.xlsx]
2021-02-20 Updated BOM yet to receive list.
    [ProjectHugo_BOM_Items_yet_to_Arrive.xlsx]
2021-02-20 Updated BOM items yet to arrive file
    [ProjectHugo_BOM_Items_yet_to_Arrive.xlsx]
2021-02-21 Update Servo Base.stl
    Increased the servo base length(added extra 11 mm) and increased the Servo screw holes diameter to 2.3 mm(Previously 1.8 mm)
    [Servo Base.stl]
2021-02-23 Update Servo Base.stl
    Reduced channel width and base lenght
    [Servo Base.stl]
2021-02-23 LED codes
2021-02-24 9 pieces 3D print file
    Directly use this file to print 9 models simultaneously. Takes 3h 41m
2021-02-24 Code modified for testing the single cube with LED servo and reed switch
2021-02-26 updated the temporary LED algorithm for single cube testing
2021-02-27 LED algorithm updated with brightness control
2021-02-27 Inverted the actuator algorithm based on the hardware.
2021-03-02 Laser Cut models of main box
2021-03-05 Create Support plate.svg
2021-03-08 Updated bsp with latest pin configuration
2021-03-08 Added servo jitter fix by adding third party library Adafruit_TiCoServo.h
    [CubeModule.hpp]
2021-03-08 Modified LED colour patterns
2021-03-08 Renamed Timers and changes the timer resolution and periods
2021-03-08 Added configurartion of all the individual boards.
2021-03-10 Added welcome note "HUGO" using NeoPixel LED
